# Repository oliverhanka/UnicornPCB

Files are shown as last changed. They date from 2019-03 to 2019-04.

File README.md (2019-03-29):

### UnicornPCB
**Unicorn shaped ESP32 and WS2812b board - CTF hardware**

This PCB has been created as a CTF hardware/badge. It features a Wemos D1 style ESP32 as well as 15 WS2812b LEDs, push button and Seeed Studios's Grove Connector for extentability. Power is obtained form the ESP32 board.

#### Hardware
Open Source Hardware

Frontside of the assembled PCB:
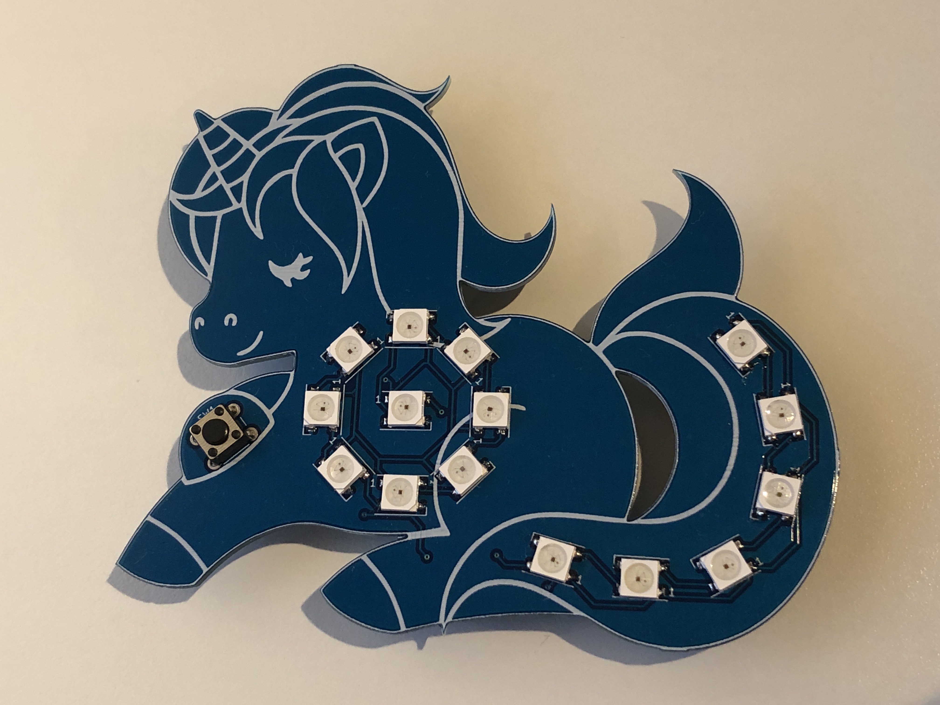
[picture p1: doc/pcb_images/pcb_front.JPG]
PCB front


Backside of the assembled PCB:
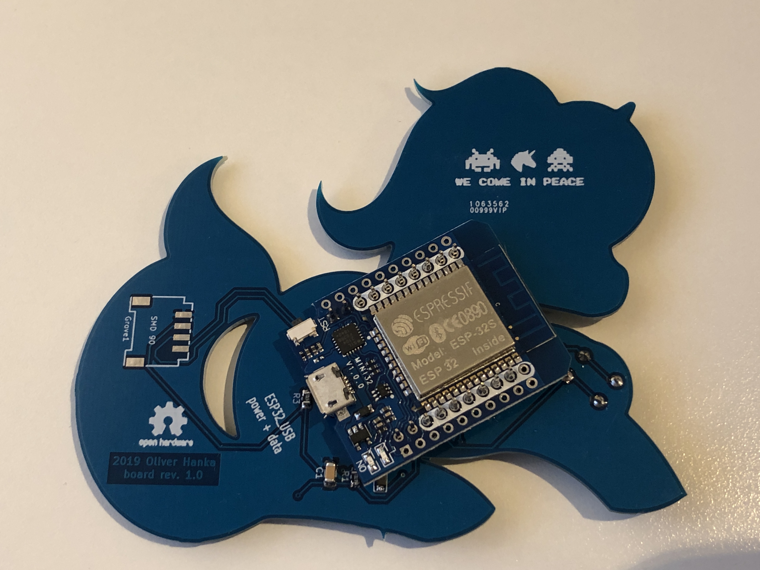
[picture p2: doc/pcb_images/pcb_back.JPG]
PCB back


#### Software
Board test firmware included. Requires ESP32 SDK and Arduino NeoPixel library.

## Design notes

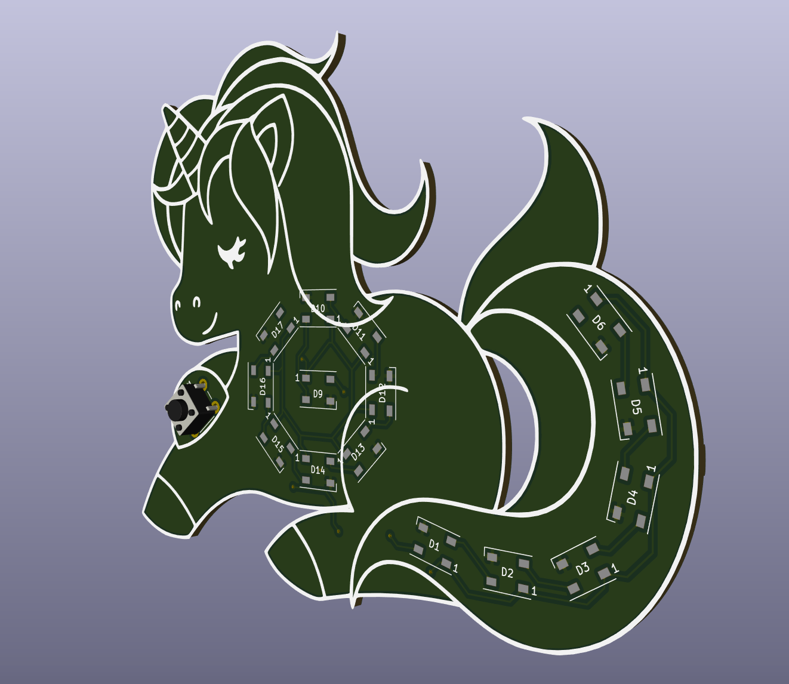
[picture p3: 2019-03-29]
doc/pcb_images/3d_front_tilted.png

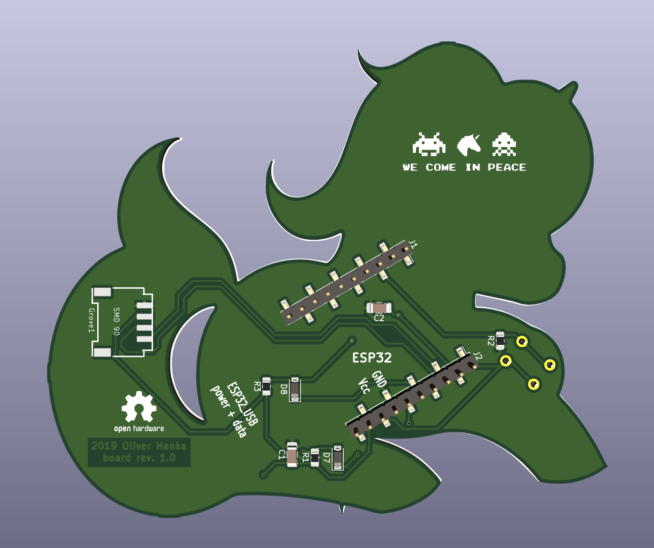
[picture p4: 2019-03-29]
doc/pcb_images/3d_back.png

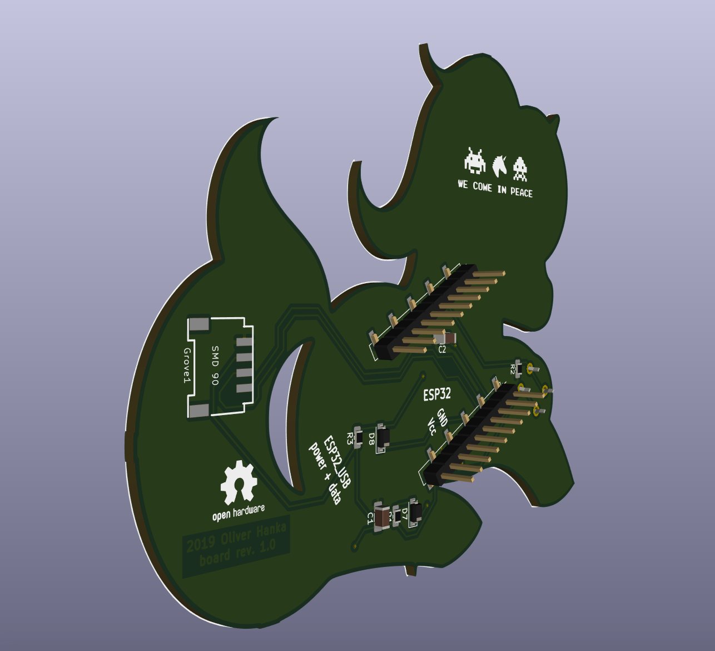
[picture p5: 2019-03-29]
doc/pcb_images/3d_back_tilted.png

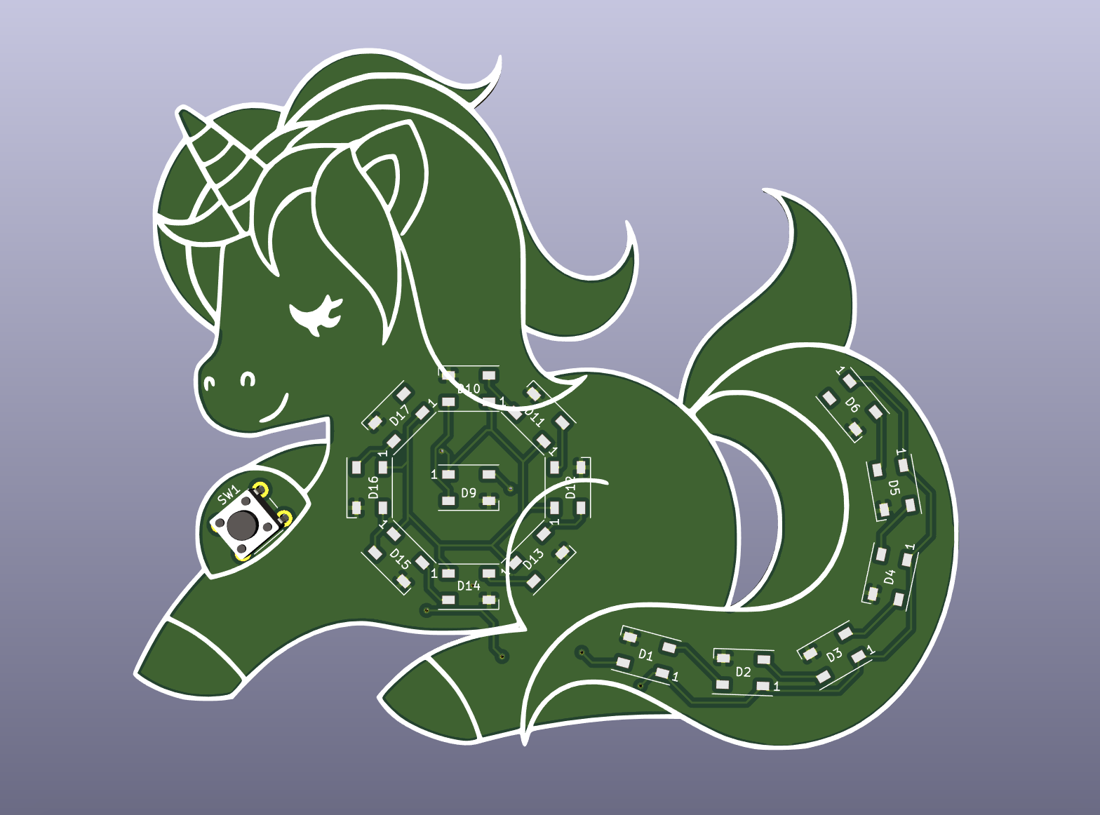
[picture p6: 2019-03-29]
doc/pcb_images/3d_front.png

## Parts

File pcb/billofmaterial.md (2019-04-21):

### Bill of material - Unicorn PCB

| Refernce | Value |
| --- | --- |
| D1-D6 | WS2812b  |
| D7-D8 | 1N4148 |
| D9-D17 | WS2812b  |
| R1, R3 | 4k7 |
| R2. | 1k |
| C1-C4 | 100nF |
| SW1 | SW_push 6x6 |
| Grove1 | Seeed GROVE connector SMD 90 |
| J1 | 1x10 male left SMD alternating |
| J2 | 1x10 male right SMD alternating |
| ESP32 | Wemos D1 style ESP32 board |

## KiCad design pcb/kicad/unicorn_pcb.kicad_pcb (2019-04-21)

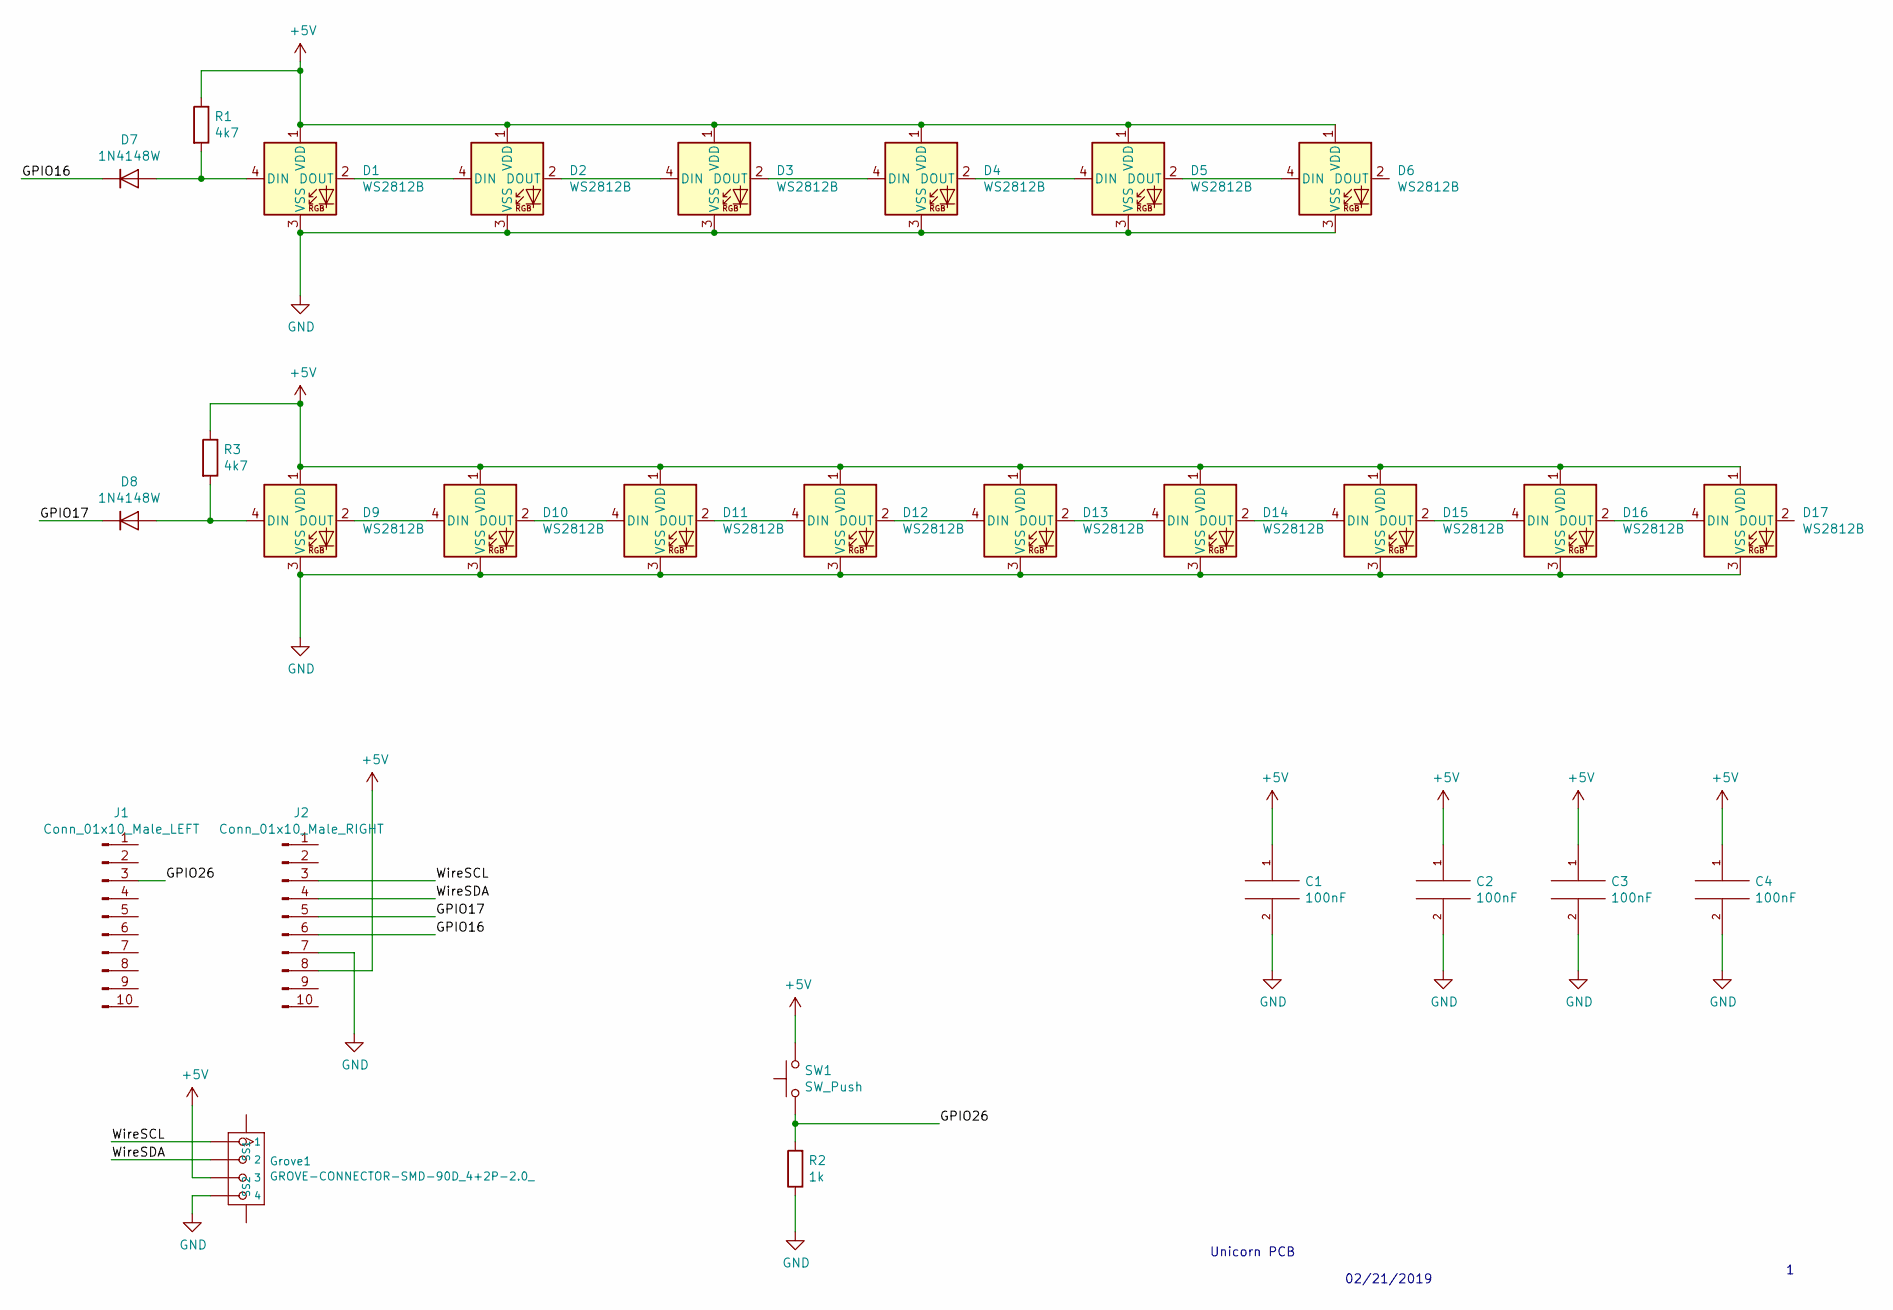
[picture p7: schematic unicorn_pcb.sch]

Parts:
C1, C2, C3, C4: 100nF; C_1206_3216Metric_Pad1.42x1.75mm_HandSolder
D1, D2, D3, D4, D5, D6, D9, D10, D11, D12, D13, D14, D15, D16, D17: WS2812B; LED_WS2812B_PLCC4_5.0x5.0mm_P3.2mm
D7, D8: 1N4148W; D_SOD-123
Grove1: GROVE-CONNECTOR-SMD-90D_4+2P-2.0_; grove-SMD-2.0-90D_new
J1: Conn_01x10_Male_LEFT; PinHeader_1x10_P2.54mm_Vertical_SMD_Pin1Right
J2: Conn_01x10_Male_RIGHT; PinHeader_1x10_P2.54mm_Vertical_SMD_Pin1Right
R1, R3: 4k7; R_0805_2012Metric_Pad1.15x1.40mm_HandSolder
R2: 1k; R_0805_2012Metric_Pad1.15x1.40mm_HandSolder
SW1: SW_Push; SW_PUSH_6mm_H5mm

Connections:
+5V: C1.1, C2.1, C3.1, C4.1, D1.1 (VDD), D2.1 (VDD), D3.1 (VDD), D4.1 (VDD), D5.1 (VDD), D6.1 (VDD), D9.1 (VDD), D10.1 (VDD), D11.1 (VDD), D12.1 (VDD), D13.1 (VDD), D14.1 (VDD), D15.1 (VDD), D16.1 (VDD), D17.1 (VDD), Grove1.3, J2.8, R1.1, R3.1, SW1.2
/GPIO16: D7.1 (K), J2.6
/GPIO17: D8.1 (K), J2.5
/GPIO26: J1.3, R2.2, SW1.1
/WireSCL: Grove1.1, J2.3
/WireSDA: Grove1.2, J2.4
GND: C1.2, C2.2, C3.2, C4.2, D1.3 (VSS), D2.3 (VSS), D3.3 (VSS), D4.3 (VSS), D5.3 (VSS), D6.3 (VSS), D9.3 (VSS), D10.3 (VSS), D11.3 (VSS), D12.3 (VSS), D13.3 (VSS), D14.3 (VSS), D15.3 (VSS), D16.3 (VSS), D17.3 (VSS), Grove1.4, J2.7, R2.1
unnamed: D1.2 (DOUT), D2.4 (DIN)
unnamed: D1.4 (DIN), D7.2 (A), R1.2
unnamed: D2.2 (DOUT), D3.4 (DIN)
unnamed: D3.2 (DOUT), D4.4 (DIN)
unnamed: D4.2 (DOUT), D5.4 (DIN)
unnamed: D5.2 (DOUT), D6.4 (DIN)
unnamed: D8.2 (A), D9.4 (DIN), R3.2
unnamed: D10.2 (DOUT), D11.4 (DIN)
unnamed: D9.2 (DOUT), D10.4 (DIN)
unnamed: D11.2 (DOUT), D12.4 (DIN)
unnamed: D12.2 (DOUT), D13.4 (DIN)
unnamed: D13.2 (DOUT), D14.4 (DIN)
unnamed: D14.2 (DOUT), D15.4 (DIN)
unnamed: D15.2 (DOUT), D16.4 (DIN)
unnamed: D16.2 (DOUT), D17.4 (DIN)

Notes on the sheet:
Unicorn PCB
02/21/2019

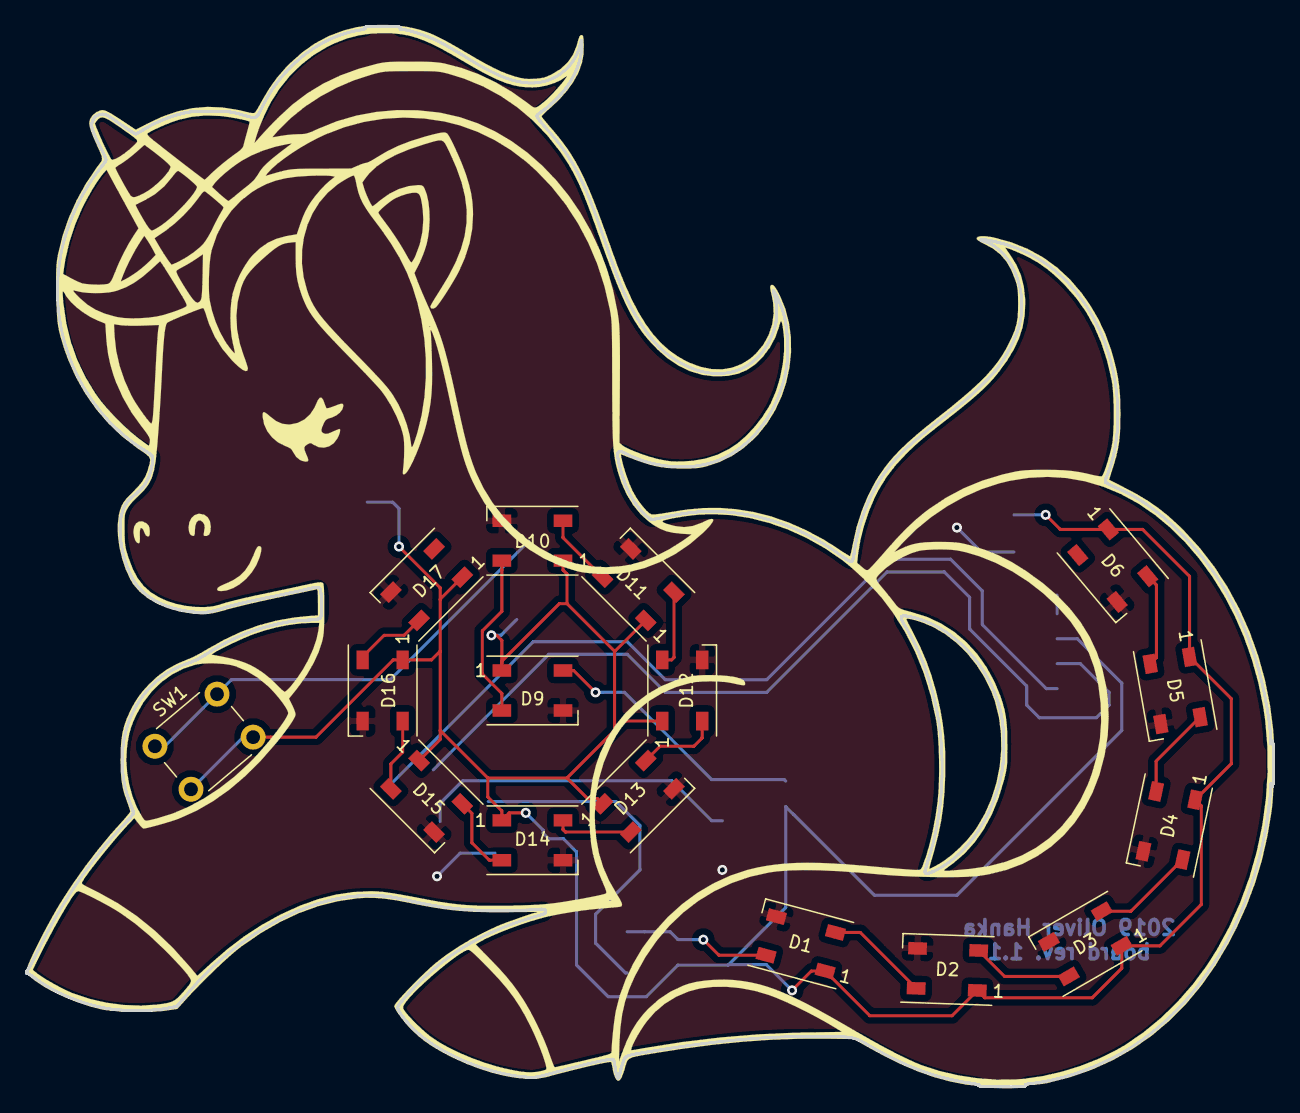
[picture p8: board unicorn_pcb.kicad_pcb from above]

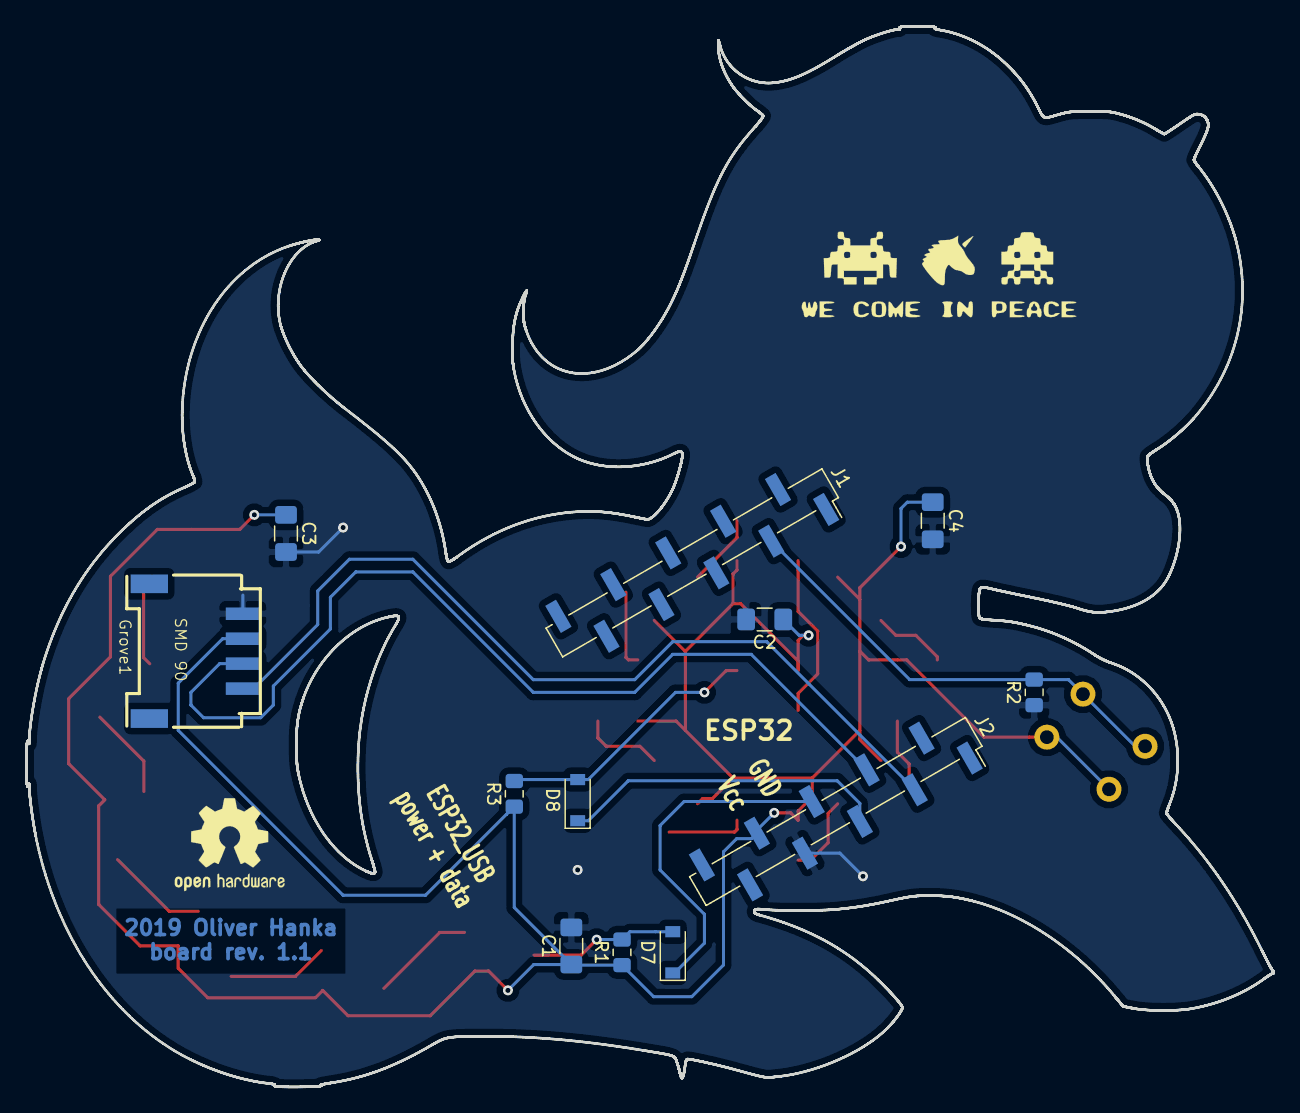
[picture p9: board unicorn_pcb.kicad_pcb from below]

Board: 2 copper layers, 100.0 x 85.0 mm, 28 parts (12 on the bottom side), 22 nets.

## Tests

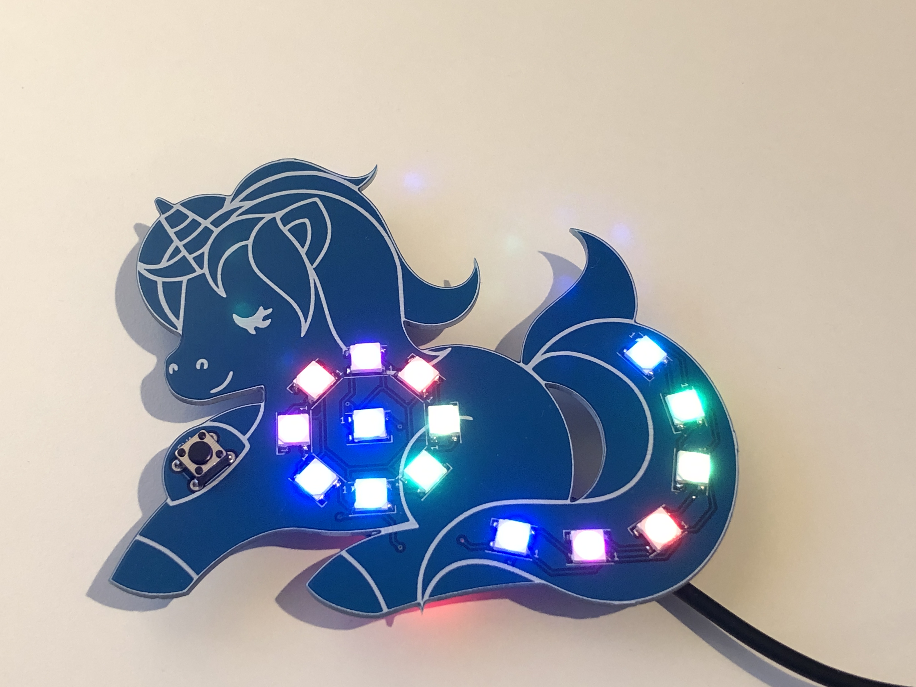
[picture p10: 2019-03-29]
doc/pcb_images/device_test.JPG

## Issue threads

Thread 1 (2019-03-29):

Push button (SW1) not working

oliverhanka, 2019-03-29:
**The backside has two GND planes of which one is not connected to GND.**

Affected by the problem:

- SW1 has a floating pull-down resistor (R2)
- Grove1 has no GND connection

_Hotfix: Connect second GND plane via wire to first GND plane (e.g., C1 GND to R2 GND)_

----

TODO:
- [x] Fix for next revision

oliverhanka, 2019-04-22:
Fixed in pcb revision 1.1

——
TODO:

- [ ] Test

Closed 2019-04-22.

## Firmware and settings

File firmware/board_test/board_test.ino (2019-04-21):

/*
 * Unicorn PCD boardice test
 * (c) 2019 Oliver Hanka - mail@oliverhanka.de
 */
 
#include <Adafruit_NeoPixel.h>
#include "Animation.h"
#include "AnimationWheel.h"
#include "AnimationRainbow.h"
#include "AnimationOff.h"
#include "config.h"

/*
 * NEO PIXEL SETUP
 */
Adafruit_NeoPixel tail_pixels = Adafruit_NeoPixel(TAIL_LED_NUM, TAIL_LED_PIN, NEO_GRB + NEO_KHZ800);
Adafruit_NeoPixel body_pixels = Adafruit_NeoPixel(BODY_LED_NUM, BODY_LED_PIN, NEO_GRB + NEO_KHZ800);

/*
 * ANIMATION SETUP
 */
#define NUM_OF_ANIMATIONS 3
Animation* animations[NUM_OF_ANIMATIONS];
AnimationWheel* animationWheel = new AnimationWheel(&body_pixels,&tail_pixels);
AnimationRainbow* rainbow = new AnimationRainbow(&body_pixels,&tail_pixels);
AnimationOff* animOff = new AnimationOff(&body_pixels,&tail_pixels);
uint8_t currentAnim;


/*
 * TIMER SETUP
 */
volatile int animTimerInterruptCounter;

hw_timer_t * animTimer = NULL;
portMUX_TYPE animTimerMux = portMUX_INITIALIZER_UNLOCKED;
 
void IRAM_ATTR onAnimTimer() {
  portENTER_CRITICAL_ISR(&animTimerMux);
  animTimerInterruptCounter++;         // record that an interrupt was fired
  portEXIT_CRITICAL_ISR(&animTimerMux);
 
}

/*
 * GPIO INTERRUPT SETUP
 */
volatile int gpioInterruptCounter = 0;
portMUX_TYPE gpioMux = portMUX_INITIALIZER_UNLOCKED;

void IRAM_ATTR handleGPIOInterrupt() {
  portENTER_CRITICAL_ISR(&gpioMux);
  gpioInterruptCounter++;             // record that an interrupt was fired
  portEXIT_CRITICAL_ISR(&gpioMux);
}

void setup() {
  Serial.begin(250000);  

  // Initialize the NeoPixel library.
  tail_pixels.begin(); 
  body_pixels.begin();
  tail_pixels.setBrightness(DEFAULT_BRIGHTNESS);
  body_pixels.setBrightness(DEFAULT_BRIGHTNESS);  

  // init animations
  animationWheel->init();
  rainbow->init();
  animOff->init();

  // set current animation
  animations[0] = animationWheel;
  animations[1] = rainbow;
  animations[2] = animOff;
  currentAnim = 0;

  // setup and start animation timer
  animTimer = timerBegin(0, 80, true);
  timerAttachInterrupt(animTimer, &onAnimTimer, true);
  timerAlarmWrite(animTimer, ANIMATION_TICK_INTERVALL, true);
  timerAlarmEnable(animTimer);

  // Register GPIO interrupt
  pinMode(SW_PIN, INPUT);
  attachInterrupt(digitalPinToInterrupt(SW_PIN), handleGPIOInterrupt, RISING);

}

void loop() {
  if (animTimerInterruptCounter > 0) {
 
    portENTER_CRITICAL(&animTimerMux);
    animTimerInterruptCounter--;
    portEXIT_CRITICAL(&animTimerMux);
 
    animations[currentAnim]->advance();
  }  
  
  if(gpioInterruptCounter > 0){
 
      portENTER_CRITICAL(&gpioMux);
      gpioInterruptCounter--;
      portEXIT_CRITICAL(&gpioMux);

      currentAnim++;
      if (currentAnim >= NUM_OF_ANIMATIONS)
        currentAnim = 0;
      animations[currentAnim]->init();
  }
}

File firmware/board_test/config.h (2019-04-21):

/* WS2812b CONFIG */
#define BODY_LED_PIN  17
#define TAIL_LED_PIN  16

#define BODY_LED_NUM  9
#define TAIL_LED_NUM  6

#define DEFAULT_BRIGHTNESS 50

/* PUSHBUTTON CONFIG */
#define SW_PIN  26

/* WLAN CONFIG */

/* ANIMATION CONFIG */
#define ANIMATION_TICK_INTERVALL (10*1000)  
